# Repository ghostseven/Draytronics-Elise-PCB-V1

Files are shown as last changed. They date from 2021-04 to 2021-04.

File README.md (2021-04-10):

# Draytronics-Elise-PCB-V1

elise  

An open source 65% mechanical keyboard, designed to be physically compatible with XD68. More info / kits / PCB designs available at https://www.draytronics.co.uk/elise

\
elisepcb

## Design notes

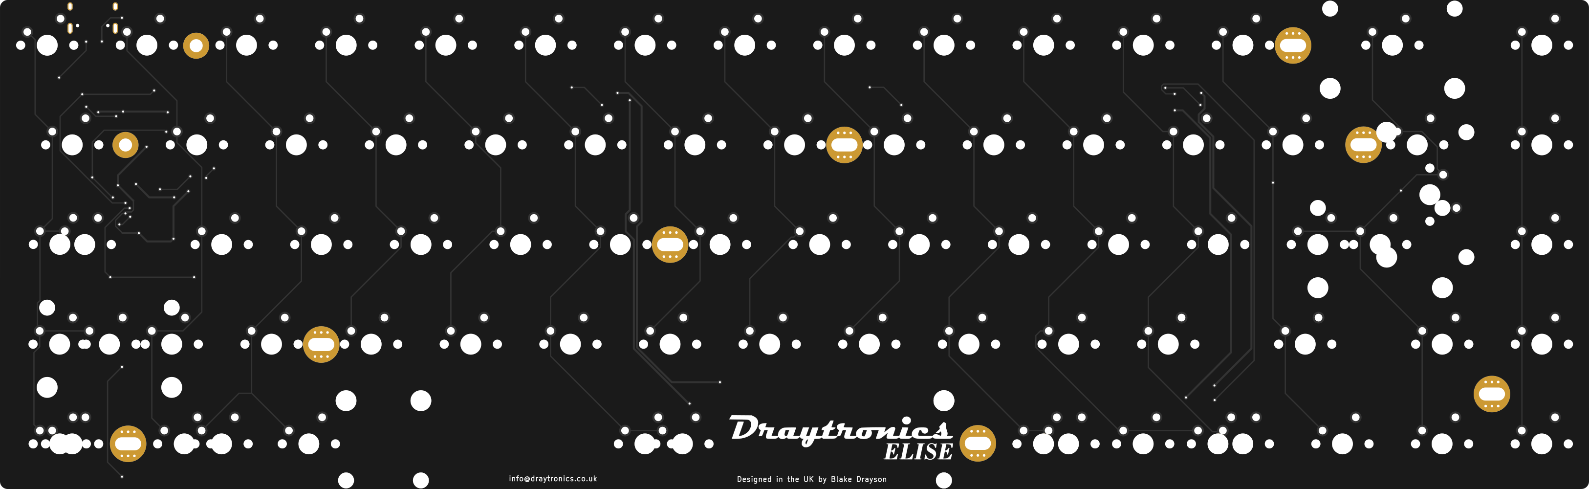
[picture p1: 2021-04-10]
Draytronics-Elise-PCB V1-top.png

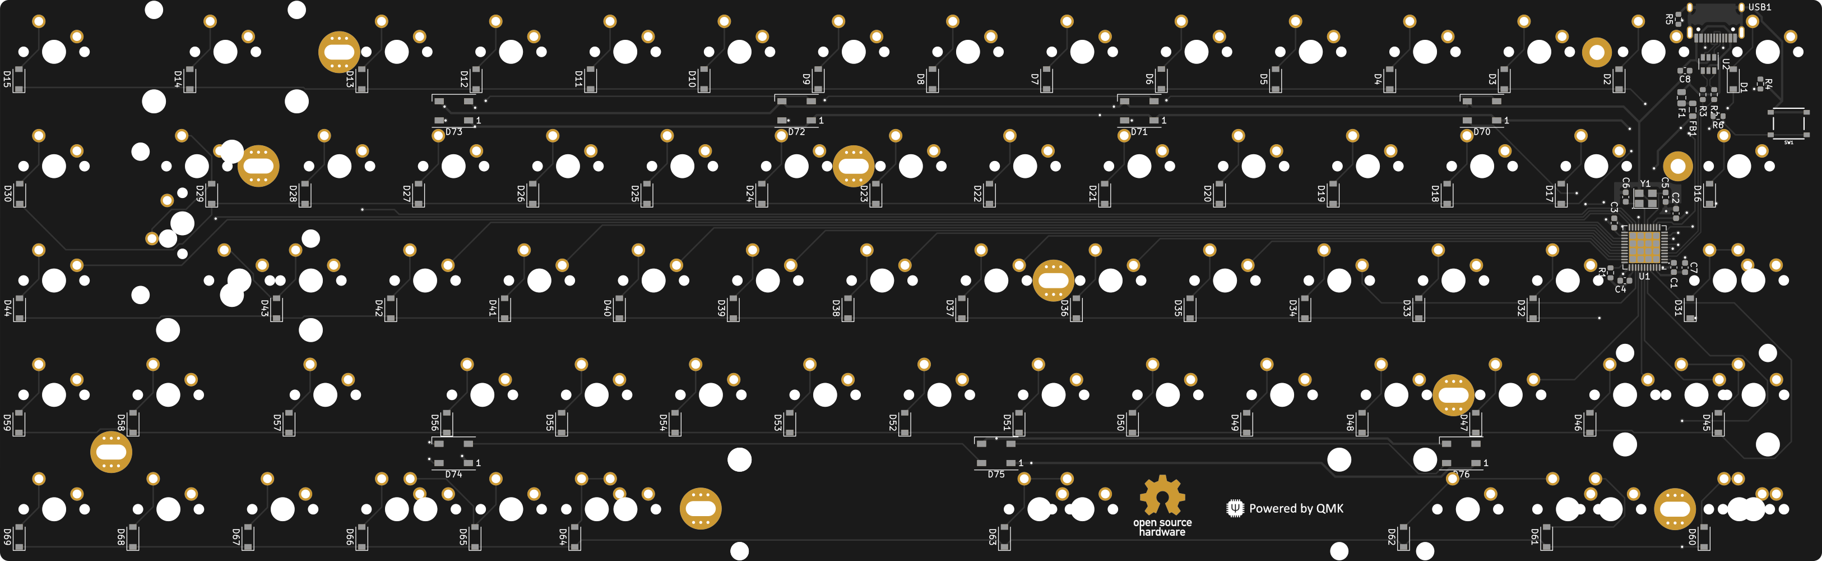
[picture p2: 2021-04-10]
Draytronics-Elise-PCB V1-bottom.png

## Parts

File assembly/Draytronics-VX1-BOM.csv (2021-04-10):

Reference | Quantity | Value | Footprint | Datasheet | LCSC Part #
C1 C2 C3 | 3 | 0.1u | Capacitor_SMD:C_0603_1608Metric | ~ | C14663
C4 | 1 | 10u | Capacitor_SMD:C_0603_1608Metric | ~ | C19702
C5 C6 | 2 | 22p | Capacitor_SMD:C_0603_1608Metric | ~ | C1653
C7 | 1 | 1u | Capacitor_SMD:C_0603_1608Metric | ~ | C15849
C8 | 1 | 4.7u | Capacitor_SMD:C_0603_1608Metric | ~ | C19666
D1 D2 D3 D4 D5 D6 D7 D8 D9 D10 D11 D12 D13 D14 D15 D16 D17 D18 D19 D20 D21 D22 D23 D24 D25 D26 D27 D28 D29 D30 D31 D32 D33 D34 D35 D36 D37 D38 D39 D40 D41 D42 D43 D44 D45 D46 D47 D48 D49 D50 D51 D52 D53 D54 D55 D56 D57 D58 D59 D60 D61 D62 D63 D64 D65 D66 D67 D68 D69 | 69 | D_Small | Diode_SMD:D_SOD-123 | ~ | C81598
D70 D71 D72 D73 D74 D75 D76 | 7 | WS2812B | LED_SMD:LED_WS2812B_PLCC4_5.0x5.0mm_P3.2mm | https://cdn-shop.adafruit.com/datasheets/WS2812B.pdf | C114586
F1 | 1 | 1A | Fuse:Fuse_0805_2012Metric | ~ | C261942
FB1 | 1 | 100r @ 100 Mhz | Inductor_SMD:L_0805_2012Metric | ~ | C1015
MX1 MX2 MX3 MX4 MX5 MX6 MX7 MX8 MX9 MX10 MX11 MX12 MX13 MX15 MX17 MX18 MX19 MX20 MX21 MX22 MX23 MX24 MX25 MX26 MX27 MX28 MX30 MX34 MX35 MX36 MX37 MX38 MX39 MX40 MX41 MX42 MX43 MX44 MX47 MX50 MX51 MX52 MX53 MX54 MX55 MX56 MX57 MX58 MX59 MX60 MX62 MX63 MX71 MX72 MX73 | 55 | MX-NoLED | MX_Only:MXOnly-1U-NoLED
MX14 | 1 | 2U | MX_Only:MXOnly-2U-NoLED
MX16 MX29 MX74 MX75 MX77 MX78 | 6 | 1.5U | MX_Only:MXOnly-1.5U-NoLED
MX31 | 1 | ISO | MX_Only:MXOnly-ISO-ROTATED-ReversedStabilizers-NoLED
MX32 MX48 MX64 MX65 MX66 | 5 | 1.25U | MX_Only:MXOnly-1.25U-NoLED
MX33 MX61 | 2 | 1.75U | MX_Only:MXOnly-1.75U-NoLED
MX46 MX68 MX69 MX70 | 4 | 1U | MX_Only:MXOnly-1U-NoLED
MX45 MX49 | 2 | 2.25U | MX_Only:MXOnly-2.25U-NoLED
MX67 | 1 | 6.25U | MX_Only:MXOnly-6.25U-ReversedStabilizers-NoLED
MX76 | 1 | 7U | MX_Only:MXOnly-7U-ReversedStabilizers-NoLED
R1 R6 | 2 | 10k | Resistor_SMD:R_0603_1608Metric | ~ | C25804
R2 R3 | 2 | 22r | Resistor_SMD:R_0603_1608Metric | ~ | C23345
R4 R5 | 2 | 5.1k | Resistor_SMD:R_0603_1608Metric | ~ | C23186
SW1 | 1 | SW_Push | Draytronics Footprints:TS-1187A-B-A-B | ~ | C318884
U1 | 1 | ATmega32U4-MU | Package_DFN_QFN:QFN-44-1EP_7x7mm_P0.5mm_EP5.2x5.2mm | http://ww1.microchip.com/downloads/en/DeviceDoc/Atmel-7766-8-bit-AVR-ATmega16U4-32U4_Datasheet.pdf | C45874
U2 | 1 | USBLC6-2SC6 | Package_TO_SOT_SMD:SOT-23-6 | https://www.st.com/resource/en/datasheet/usblc6-2.pdf | C7519
USB1 | 1 | HRO-TYPE-C-31-M-12 | Type-C:HRO-TYPE-C-31-M-12-Assembly |  | C165948
Y1 | 1 | 16MHz | Crystal:Crystal_SMD_3225-4Pin_3.2x2.5mm | ~ | C13738

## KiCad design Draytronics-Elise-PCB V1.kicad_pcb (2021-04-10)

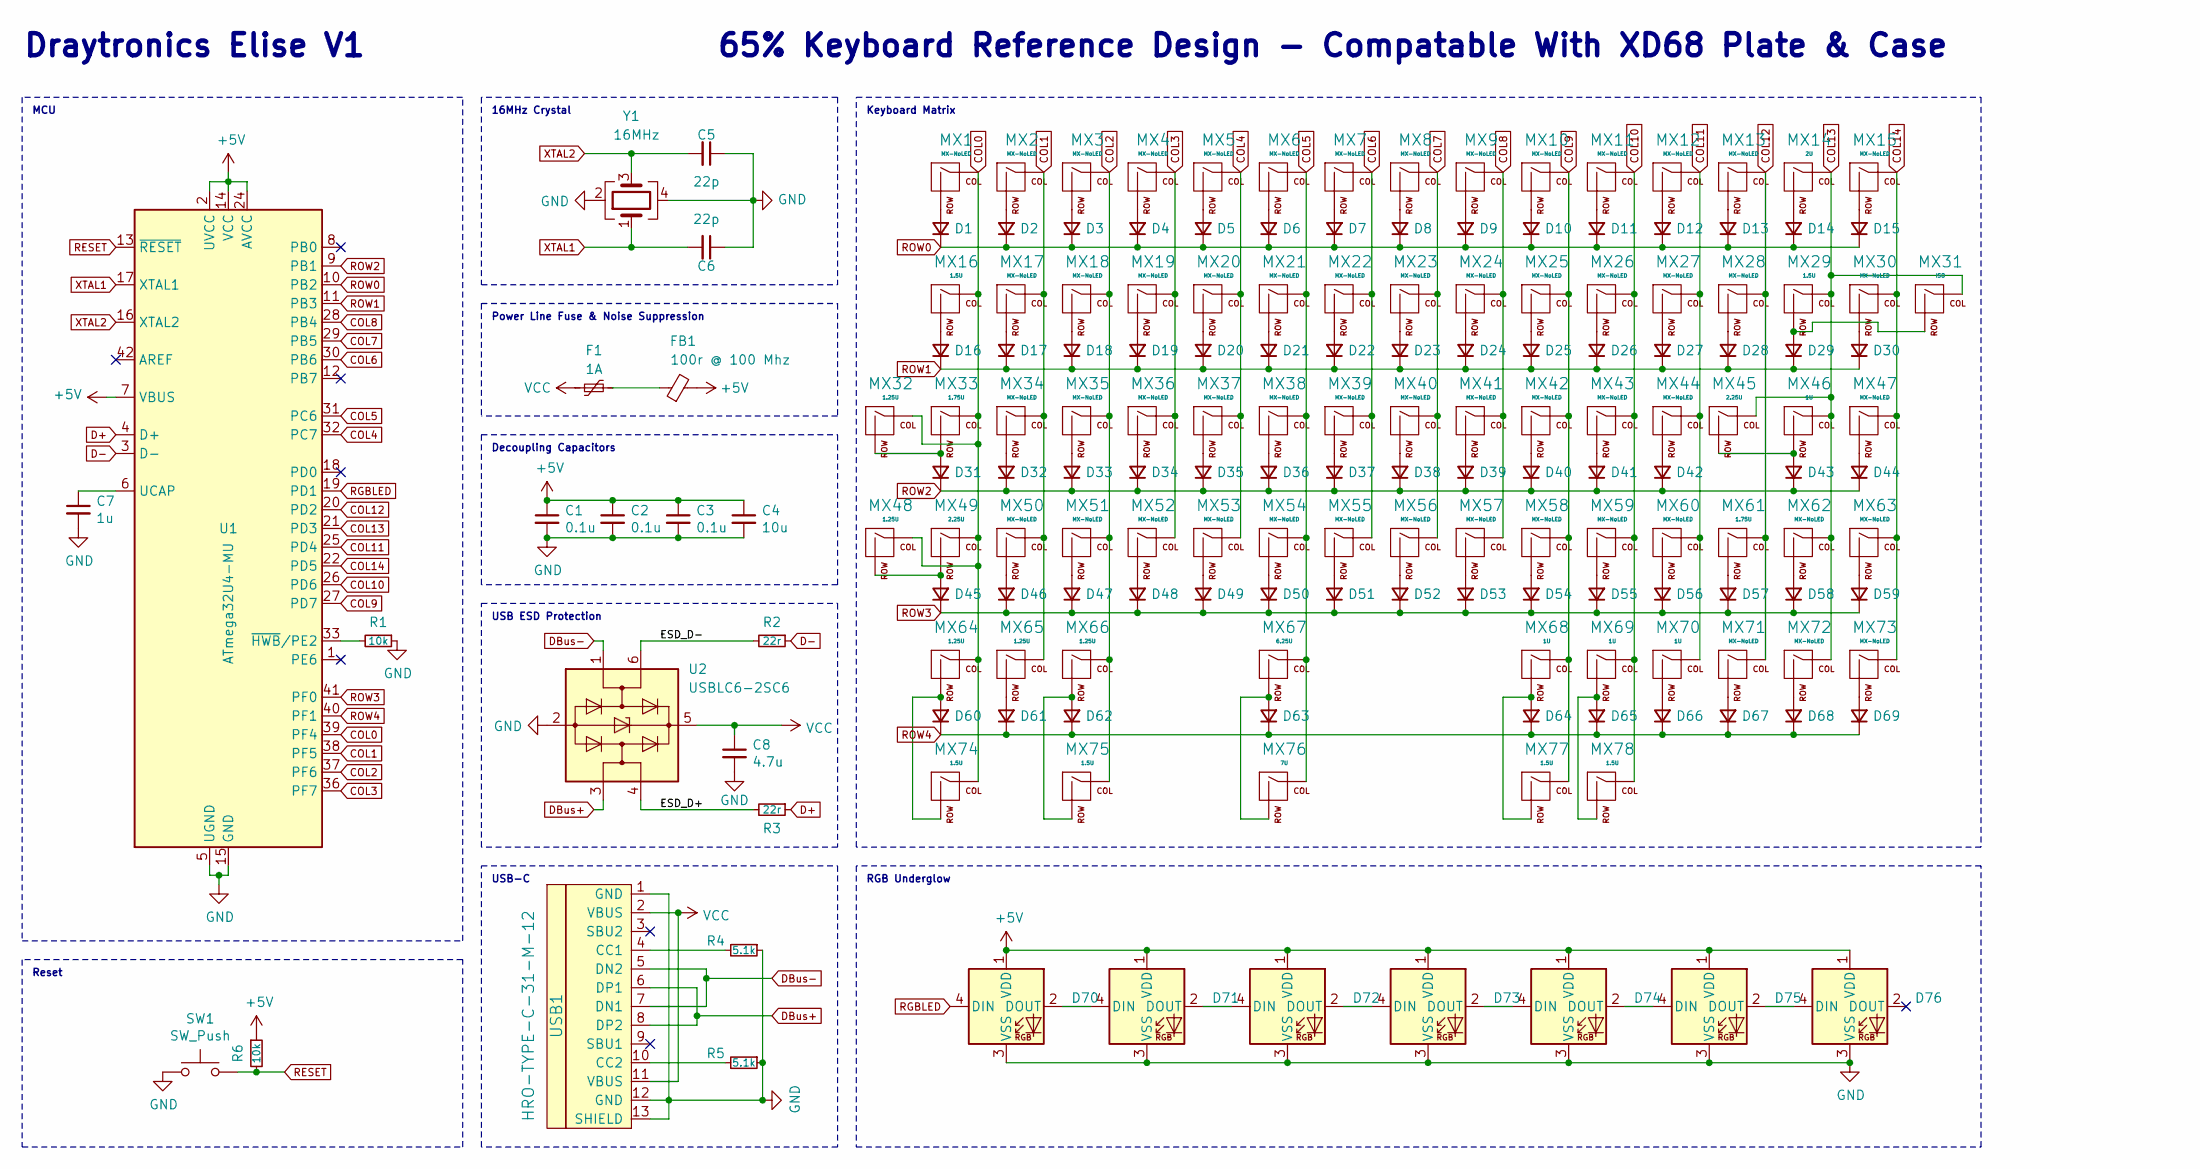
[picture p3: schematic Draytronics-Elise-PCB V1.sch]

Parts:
C1, C2, C3: 0.1u; C_0603_1608Metric; LCSC Part # C14663
C4: 10u; C_0603_1608Metric; LCSC Part # C19702
C5, C6: 22p; C_0603_1608Metric; LCSC Part # C1653
C7: 1u; C_0603_1608Metric; LCSC Part # C15849
C8: 4.7u; C_0603_1608Metric; LCSC Part # C19666
D1, D2, D3, D4, D5, D6, D7, D8, D9, D10, D11, D12, D13, D14, D15, D16, D17, D18, D19, D20, D21, D22, D23, D24, D25, D26, D27, D28, D29, D30, D31, D32, D33, D34, D35, D36, D37, D38, D39, D40, D41, D42, D43, D44, D45, D46, D47, D48, D49, D50, D51, D52, D53, D54, D55, D56, D57, D58, D59, D60, D61, D62, D63, D64, D65, D66, D67, D68, D69: D_Small; D_SOD-123; LCSC Part # C81598
D70, D71, D72, D73, D74, D75, D76: WS2812B; LED_WS2812B_PLCC4_5.0x5.0mm_P3.2mm; LCSC Part # C114586
F1: 1A; Fuse_0805_2012Metric; LCSC Part # C261942
FB1: 100r @ 100 Mhz; L_0805_2012Metric; LCSC Part # C1015
MX1, MX2, MX3, MX4, MX5, MX6, MX7, MX8, MX9, MX10, MX11, MX12, MX13, MX15, MX17, MX18, MX19, MX20, MX21, MX22, MX23, MX24, MX25, MX26, MX27, MX28, MX30, MX34, MX35, MX36, MX37, MX38, MX39, MX40, MX41, MX42, MX43, MX44, MX47, MX50, MX51, MX52, MX53, MX54, MX55, MX56, MX57, MX58, MX59, MX60, MX62, MX63, MX71, MX72, MX73: MX-NoLED; MXOnly-1U-NoLED
MX14: 2U; MXOnly-2U-NoLED
MX16, MX29, MX74, MX75, MX77, MX78: 1.5U; MXOnly-1.5U-NoLED
MX31: ISO; MXOnly-ISO-ROTATED-ReversedStabilizers-NoLED
MX32, MX48, MX64, MX65, MX66: 1.25U; MXOnly-1.25U-NoLED
MX33, MX61: 1.75U; MXOnly-1.75U-NoLED
MX45, MX49: 2.25U; MXOnly-2.25U-NoLED
MX46, MX68, MX69, MX70: 1U; MXOnly-1U-NoLED
MX67: 6.25U; MXOnly-6.25U-ReversedStabilizers-NoLED
MX76: 7U; MXOnly-7U-ReversedStabilizers-NoLED
R1, R6: 10k; R_0603_1608Metric; LCSC Part # C25804
R2, R3: 22r; R_0603_1608Metric; LCSC Part # C23345
R4, R5: 5.1k; R_0603_1608Metric; LCSC Part # C23186
SW1: SW_Push; TS-1187A-B-A-B; LCSC Part # C318884
U1: ATmega32U4-MU; QFN-44-1EP_7x7mm_P0.5mm_EP5.2x5.2mm; LCSC Part # C45874
U2: USBLC6-2SC6; SOT-23-6; LCSC Part # C7519
USB1: HRO-TYPE-C-31-M-12; HRO-TYPE-C-31-M-12-Assembly; LCSC Part # C165948
Y1: 16MHz; Crystal_SMD_3225-4Pin_3.2x2.5mm; LCSC Part # C13738

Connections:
+5V: C1.1, C2.1, C3.1, C4.1, D70.1 (VDD), D71.1 (VDD), D72.1 (VDD), D73.1 (VDD), D74.1 (VDD), D75.1 (VDD), D76.1 (VDD), FB1.2, R6.1, U1.2 (UVCC), U1.7 (VBUS), U1.14 (VCC), U1.24 (AVCC), U1.34 (VCC), U1.44 (AVCC)
/ESD_D+: R3.2, U2.4 (I/O2)
/ESD_D-: R2.2, U2.6 (I/O1)
COL0: MX1.1 (COL), MX16.1 (COL), MX32.1 (COL), MX33.1 (COL), MX48.1 (COL), MX49.1 (COL), MX64.1 (COL), MX74.1 (COL), U1.39 (PF4)
COL1: MX2.1 (COL), MX17.1 (COL), MX34.1 (COL), MX50.1 (COL), MX65.1 (COL), U1.38 (PF5)
COL2: MX3.1 (COL), MX18.1 (COL), MX35.1 (COL), MX51.1 (COL), MX66.1 (COL), MX75.1 (COL), U1.37 (PF6)
COL3: MX4.1 (COL), MX19.1 (COL), MX36.1 (COL), MX52.1 (COL), U1.36 (PF7)
COL4: MX5.1 (COL), MX20.1 (COL), MX37.1 (COL), MX53.1 (COL), U1.32 (PC7)
COL5: MX6.1 (COL), MX21.1 (COL), MX38.1 (COL), MX54.1 (COL), MX67.1 (COL), MX76.1 (COL), U1.31 (PC6)
COL6: MX7.1 (COL), MX22.1 (COL), MX39.1 (COL), MX55.1 (COL), U1.30 (PB6)
COL7: MX8.1 (COL), MX23.1 (COL), MX40.1 (COL), MX56.1 (COL), U1.29 (PB5)
COL8: MX9.1 (COL), MX24.1 (COL), MX41.1 (COL), MX57.1 (COL), U1.28 (PB4)
COL9: MX10.1 (COL), MX25.1 (COL), MX42.1 (COL), MX58.1 (COL), MX68.1 (COL), MX77.1 (COL), U1.27 (PD7)
COL10: MX11.1 (COL), MX26.1 (COL), MX43.1 (COL), MX59.1 (COL), MX69.1 (COL), MX78.1 (COL), U1.26 (PD6)
COL11: MX12.1 (COL), MX27.1 (COL), MX44.1 (COL), MX60.1 (COL), MX70.1 (COL), U1.25 (PD4)
COL12: MX13.1 (COL), MX28.1 (COL), MX61.1 (COL), MX71.1 (COL), U1.20 (PD2)
COL13: MX14.1 (COL), MX29.1 (COL), MX31.1 (COL), MX45.1 (COL), MX46.1 (COL), MX62.1 (COL), MX72.1 (COL), U1.21 (PD3)
COL14: MX15.1 (COL), MX30.1 (COL), MX47.1 (COL), MX63.1 (COL), MX73.1 (COL), U1.22 (PD5)
D+: R3.1, U1.4 (D+)
D-: R2.1, U1.3 (D-)
DBus+: U2.3 (I/O2), USB1.6 (DP1), USB1.8 (DP2)
DBus-: U2.1 (I/O1), USB1.5 (DN2), USB1.7 (DN1)
GND: C1.2, C2.2, C3.2, C4.2, C5.1, C6.1, C7.2, C8.2, D70.3 (VSS), D71.3 (VSS), D72.3 (VSS), D73.3 (VSS), D74.3 (VSS), D75.3 (VSS), D76.3 (VSS), R1.1, R4.1, R5.1, SW1.1, U1.5 (UGND), U1.15 (GND), U1.23 (GND), U1.35 (GND), U1.43 (GND), U1.45 (GND), U2.2 (GND), USB1.1 (GND), USB1.12 (GND), USB1.13 (SHIELD), Y1.2, Y1.4
unnamed: C7.1, U1.6 (UCAP)
unnamed: D1.2 (A), MX1.2 (ROW)
unnamed: D2.2 (A), MX2.2 (ROW)
unnamed: D3.2 (A), MX3.2 (ROW)
unnamed: D4.2 (A), MX4.2 (ROW)
unnamed: D5.2 (A), MX5.2 (ROW)
unnamed: D6.2 (A), MX6.2 (ROW)
unnamed: D7.2 (A), MX7.2 (ROW)
unnamed: D8.2 (A), MX8.2 (ROW)
unnamed: D9.2 (A), MX9.2 (ROW)
unnamed: D10.2 (A), MX10.2 (ROW)
unnamed: D11.2 (A), MX11.2 (ROW)
unnamed: D12.2 (A), MX12.2 (ROW)
unnamed: D13.2 (A), MX13.2 (ROW)
unnamed: D14.2 (A), MX14.2 (ROW)
unnamed: D15.2 (A), MX15.2 (ROW)
unnamed: D16.2 (A), MX16.2 (ROW)
unnamed: D17.2 (A), MX17.2 (ROW)
unnamed: D18.2 (A), MX18.2 (ROW)
unnamed: D19.2 (A), MX19.2 (ROW)
unnamed: D20.2 (A), MX20.2 (ROW)
unnamed: D21.2 (A), MX21.2 (ROW)
unnamed: D22.2 (A), MX22.2 (ROW)
unnamed: D23.2 (A), MX23.2 (ROW)
unnamed: D24.2 (A), MX24.2 (ROW)
unnamed: D25.2 (A), MX25.2 (ROW)
unnamed: D26.2 (A), MX26.2 (ROW)
unnamed: D27.2 (A), MX27.2 (ROW)
unnamed: D28.2 (A), MX28.2 (ROW)
unnamed: D29.2 (A), MX29.2 (ROW), MX31.2 (ROW)
unnamed: D30.2 (A), MX30.2 (ROW)
unnamed: D31.2 (A), MX32.2 (ROW), MX33.2 (ROW)
unnamed: D32.2 (A), MX34.2 (ROW)
unnamed: D33.2 (A), MX35.2 (ROW)
unnamed: D34.2 (A), MX36.2 (ROW)
unnamed: D35.2 (A), MX37.2 (ROW)
unnamed: D36.2 (A), MX38.2 (ROW)
unnamed: D37.2 (A), MX39.2 (ROW)
unnamed: D38.2 (A), MX40.2 (ROW)
unnamed: D39.2 (A), MX41.2 (ROW)
unnamed: D40.2 (A), MX42.2 (ROW)
unnamed: D41.2 (A), MX43.2 (ROW)
unnamed: D42.2 (A), MX44.2 (ROW)
unnamed: D43.2 (A), MX45.2 (ROW), MX46.2 (ROW)
unnamed: D44.2 (A), MX47.2 (ROW)
unnamed: D45.2 (A), MX48.2 (ROW), MX49.2 (ROW)
unnamed: D46.2 (A), MX50.2 (ROW)
unnamed: D47.2 (A), MX51.2 (ROW)
unnamed: D48.2 (A), MX52.2 (ROW)
unnamed: D49.2 (A), MX53.2 (ROW)
unnamed: D50.2 (A), MX54.2 (ROW)
unnamed: D51.2 (A), MX55.2 (ROW)
unnamed: D52.2 (A), MX56.2 (ROW)
unnamed: D53.2 (A), MX57.2 (ROW)
unnamed: D54.2 (A), MX58.2 (ROW)
unnamed: D55.2 (A), MX59.2 (ROW)
unnamed: D56.2 (A), MX60.2 (ROW)
unnamed: D57.2 (A), MX61.2 (ROW)
unnamed: D58.2 (A), MX62.2 (ROW)
unnamed: D59.2 (A), MX63.2 (ROW)
unnamed: D60.2 (A), MX64.2 (ROW), MX74.2 (ROW)
unnamed: D61.2 (A), MX65.2 (ROW)
unnamed: D62.2 (A), MX66.2 (ROW), MX75.2 (ROW)
unnamed: D63.2 (A), MX67.2 (ROW), MX76.2 (ROW)
unnamed: D64.2 (A), MX68.2 (ROW), MX77.2 (ROW)
unnamed: D65.2 (A), MX69.2 (ROW), MX78.2 (ROW)
unnamed: D66.2 (A), MX70.2 (ROW)
unnamed: D67.2 (A), MX71.2 (ROW)
unnamed: D68.2 (A), MX72.2 (ROW)
unnamed: D69.2 (A), MX73.2 (ROW)
unnamed: D70.2 (DOUT), D71.4 (DIN)
unnamed: D71.2 (DOUT), D72.4 (DIN)
unnamed: D72.2 (DOUT), D73.4 (DIN)
unnamed: D73.2 (DOUT), D74.4 (DIN)
unnamed: D74.2 (DOUT), D75.4 (DIN)
unnamed: D75.2 (DOUT), D76.4 (DIN)
unnamed: F1.2, FB1.1
unnamed: R1.2, U1.33 (~HWB~/PE2)
unnamed: R4.2, USB1.4 (CC1)
unnamed: R5.2, USB1.10 (CC2)
RESET: R6.2, SW1.2, U1.13 (~RESET)
RGBLED: D70.4 (DIN), U1.19 (PD1)
ROW0: D1.1 (K), D2.1 (K), D3.1 (K), D4.1 (K), D5.1 (K), D6.1 (K), D7.1 (K), D8.1 (K), D9.1 (K), D10.1 (K), D11.1 (K), D12.1 (K), D13.1 (K), D14.1 (K), D15.1 (K), U1.10 (PB2)
ROW1: D16.1 (K), D17.1 (K), D18.1 (K), D19.1 (K), D20.1 (K), D21.1 (K), D22.1 (K), D23.1 (K), D24.1 (K), D25.1 (K), D26.1 (K), D27.1 (K), D28.1 (K), D29.1 (K), D30.1 (K), U1.11 (PB3)
ROW2: D31.1 (K), D32.1 (K), D33.1 (K), D34.1 (K), D35.1 (K), D36.1 (K), D37.1 (K), D38.1 (K), D39.1 (K), D40.1 (K), D41.1 (K), D42.1 (K), D43.1 (K), D44.1 (K), U1.9 (PB1)
ROW3: D45.1 (K), D46.1 (K), D47.1 (K), D48.1 (K), D49.1 (K), D50.1 (K), D51.1 (K), D52.1 (K), D53.1 (K), D54.1 (K), D55.1 (K), D56.1 (K), D57.1 (K), D58.1 (K), D59.1 (K), U1.41 (PF0)
ROW4: D60.1 (K), D61.1 (K), D62.1 (K), D63.1 (K), D64.1 (K), D65.1 (K), D66.1 (K), D67.1 (K), D68.1 (K), D69.1 (K), U1.40 (PF1)
VCC: C8.1, F1.1, U2.5 (VBUS), USB1.2 (VBUS), USB1.11 (VBUS)
XTAL1: C6.2, U1.17 (XTAL1), Y1.1
XTAL2: C5.2, U1.16 (XTAL2), Y1.3

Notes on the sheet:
Keyboard Matrix
16MHz Crystal
Power Line Fuse & Noise Suppression
Decoupling Capacitors
USB ESD Protection
RGB Underglow
USB-C
Reset
MCU
Draytronics Elise V1
65% Keyboard Reference Design - Compatable With XD68 Plate & Case

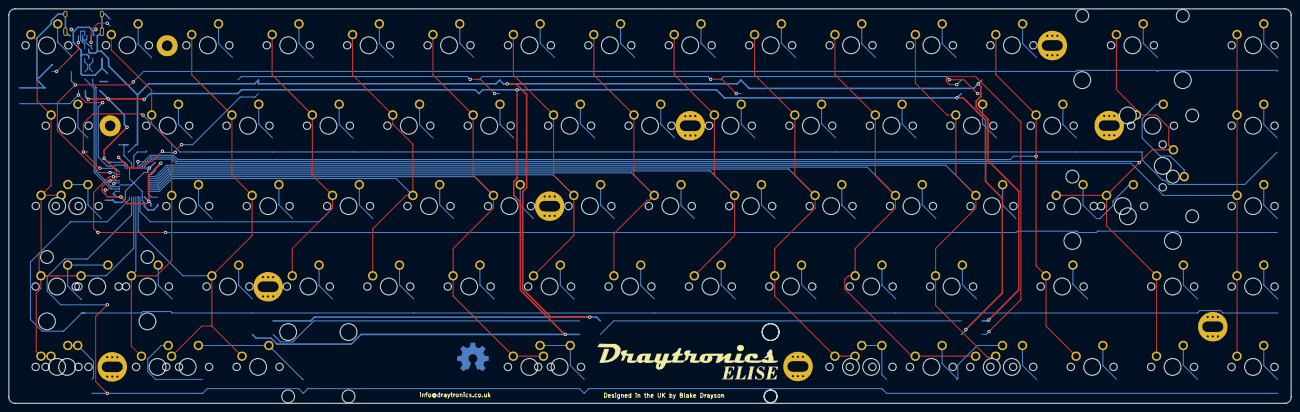
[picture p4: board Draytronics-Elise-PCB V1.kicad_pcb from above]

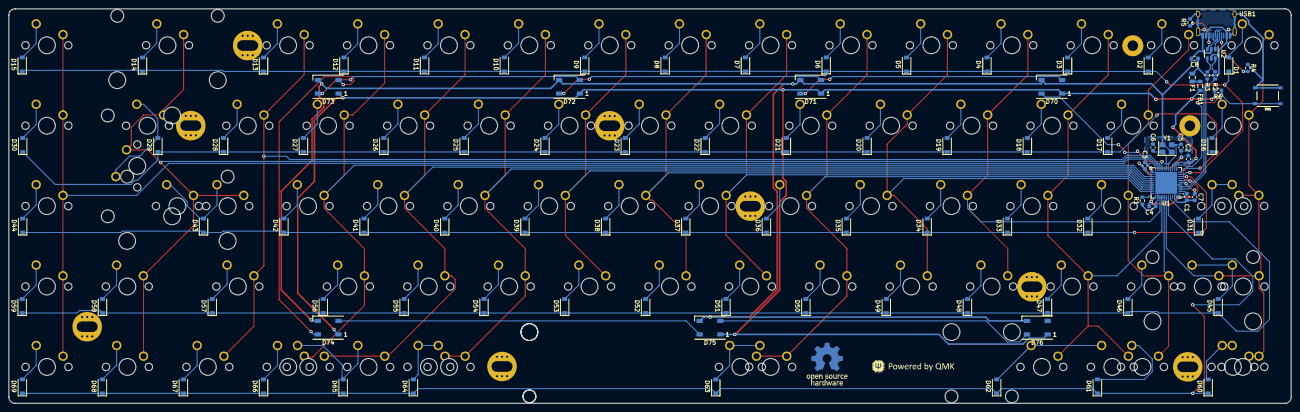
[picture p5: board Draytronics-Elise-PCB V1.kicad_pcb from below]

Board: 2 copper layers, 303.8 x 93.5 mm, 175 parts (97 on the bottom side), 113 nets.
